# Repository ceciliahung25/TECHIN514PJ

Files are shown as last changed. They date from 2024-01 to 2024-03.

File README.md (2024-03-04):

# Echoes of Space

## Cecilia Hung (2320001)

For a detailed view of the power consumption calculations and system profiles, you can view the spreadsheet here:
[View the Power Consumption Spreadsheet](https://docs.google.com/spreadsheets/d/1GH_dmqcpy9LyMxHUE3kLtBWBAWlxp0ul/edit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)
This spreadsheet includes all the power metrics used in the project and the estimated days of use for each component.

### Sensing the Unseen: A Symphony in Silence

In the vast tapestry of everyday life, sounds weave invisible threads, creating a symphony often unheard and unseen. "Echoes of Space" is an odyssey into making the imperceptible palpable, visualizing the whispers and roars of our environment, and transforming them into a visual serenade.

### Sensing Device: Whisperer of the Unheard Symphony

The Sensing Device is engineered to capture ambient noise with precision and transmit this data for further processing. It serves as the primary data collection unit in diverse settings.

### Display Device: Illuminator of the Unseen Resonance

The Display Device is tasked with receiving acoustic data and rendering it into a visual format. It utilizes a range of components to articulate the nuances of environmental sound.

### Components

- **Sensing Device**
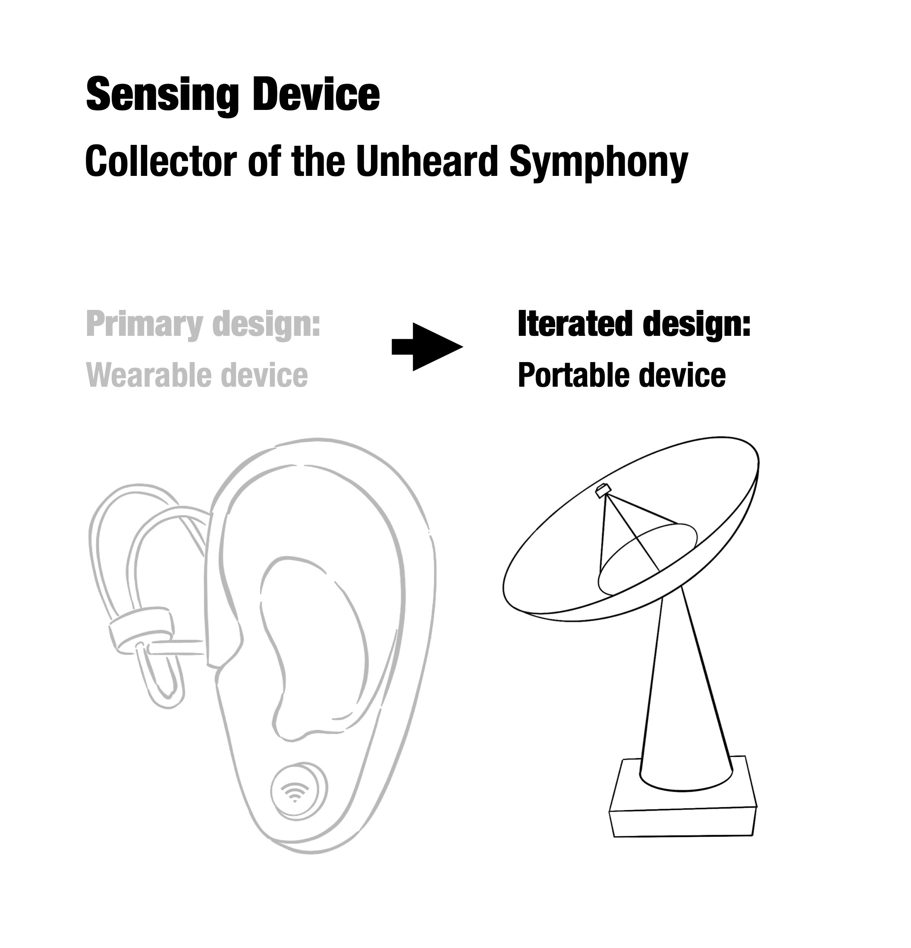
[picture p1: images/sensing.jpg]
Sensing Device

  - Microcontroller: Seeed Xiao ESP32S3
  - Microphone: Seeed Xiao ESP32S3 Sense Expansion Board Microphone
  - Interface: Adafruit Tactile Switch Button (12mm Square, 6mm Tall)

- **Display Device**
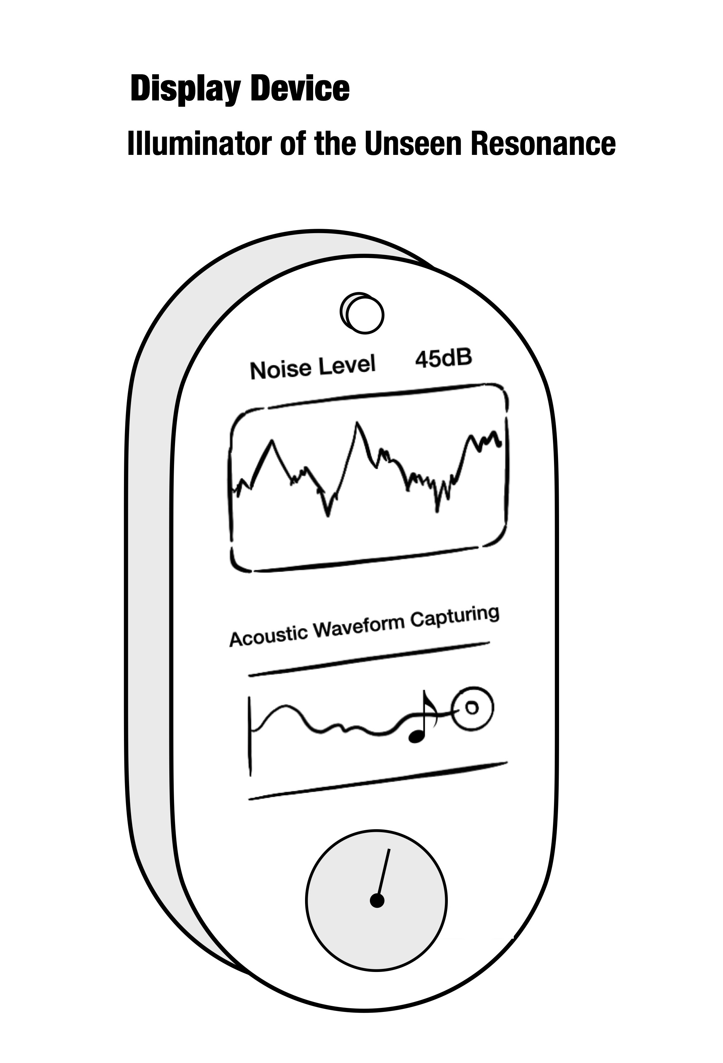
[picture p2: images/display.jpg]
Display Device

  - Microcontroller: Seeed Xiao ESP32S3
  - Display: OLED SSD1306
  - User Interface: Adafruit SPDT Slide Switch
  - Output Actuator: Stepper Motor (JST X27.168)
  - Power Source: 3.7V Lipo Battery 1000mAh

### System Architecture Diagram
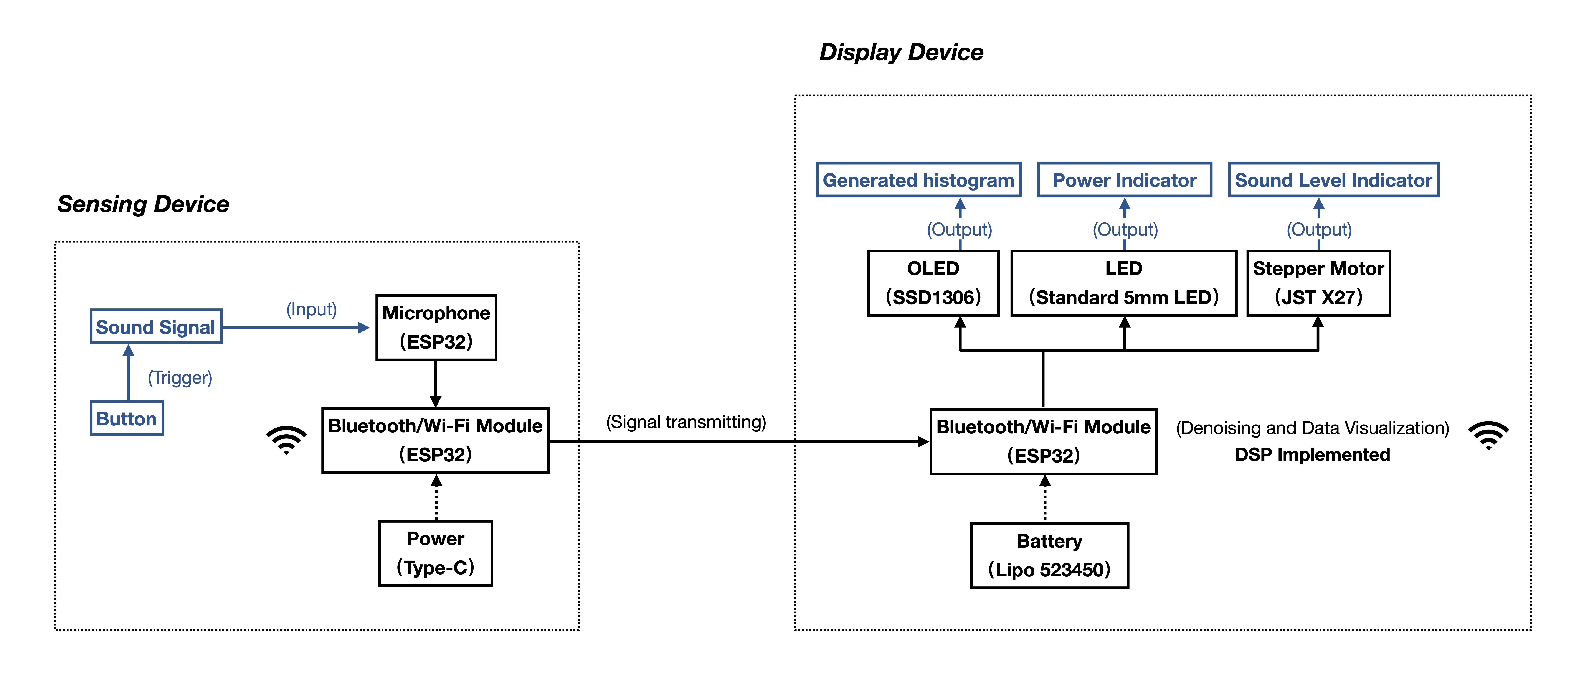
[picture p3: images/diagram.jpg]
System Architecture


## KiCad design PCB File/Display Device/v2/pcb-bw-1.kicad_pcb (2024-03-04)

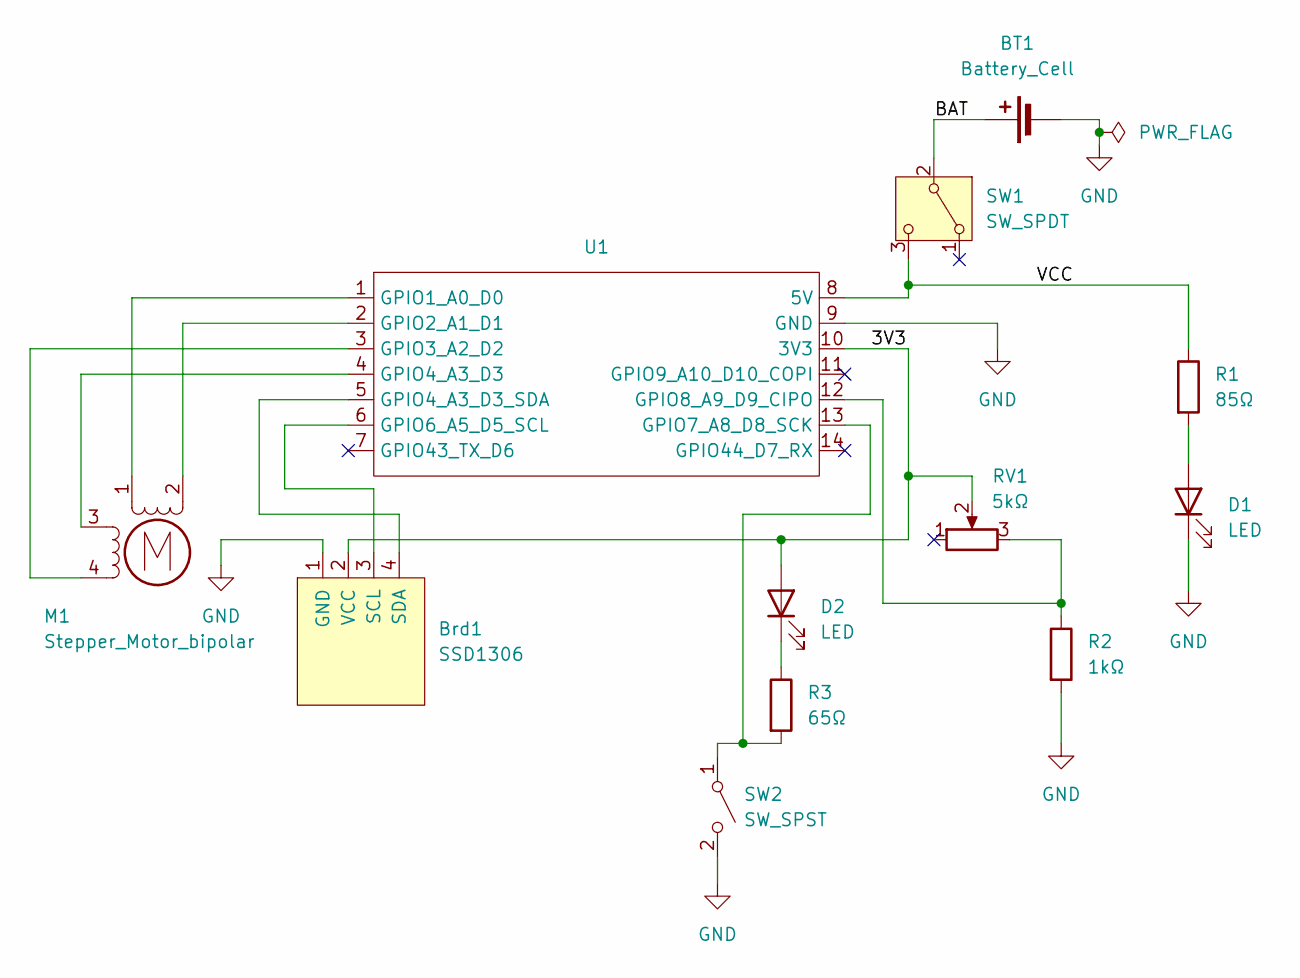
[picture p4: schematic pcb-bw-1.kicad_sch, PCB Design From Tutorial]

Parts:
BT1: Battery_Cell; JST_NV_B02P-NV_1x02_P5.00mm_Vertical
Brd1: SSD1306; 128x64OLED
D1, D2: LED; LED_0805_2012Metric_Pad1.15x1.40mm_HandSolder
M1: Stepper_Motor_bipolar; x27_stepper
R1: 85Ω; R_0805_2012Metric_Pad1.20x1.40mm_HandSolder
R2: 1kΩ; R_0805_2012Metric_Pad1.20x1.40mm_HandSolder
R3: 65Ω; R_0805_2012Metric_Pad1.20x1.40mm_HandSolder
RV1: 5kΩ; Potentiometer_Piher_PC-16_Single_Horizontal
SW1: SW_SPDT; JST_EH_B3B-EH-A_1x03_P2.50mm_Vertical
SW2: SW_SPST; SW_PUSH-12mm
U1: XIAO_ESP32_SENSE

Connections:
/3V3: Brd1.2 (VCC), D2.2 (A), RV1.2, U1.10 (3V3)
/BAT: BT1.1 (+), SW1.2 (B)
/VCC: R1.1, SW1.3 (C), U1.8 (5V)
GND: BT1.2 (-), Brd1.1 (GND), D1.1 (K), R2.2, SW2.2 (B), U1.9 (GND)
unnamed: Brd1.3 (SCL), U1.6 (GPIO6_A5_D5_SCL)
unnamed: Brd1.4 (SDA), U1.5 (GPIO4_A3_D3_SDA)
unnamed: D1.2 (A), R1.2
unnamed: D2.1 (K), R3.1
unnamed: M1.2 (-), U1.2 (GPIO2_A1_D1)
unnamed: R3.2, SW2.1 (A), U1.13 (GPIO7_A8_D8_SCK)
unnamed: M1.1, U1.1 (GPIO1_A0_D0)
unnamed: M1.4, U1.3 (GPIO3_A2_D2)
unnamed: M1.3, U1.4 (GPIO4_A3_D3)
unnamed: R2.1, RV1.3, U1.12 (GPIO8_A9_D9_CIPO)

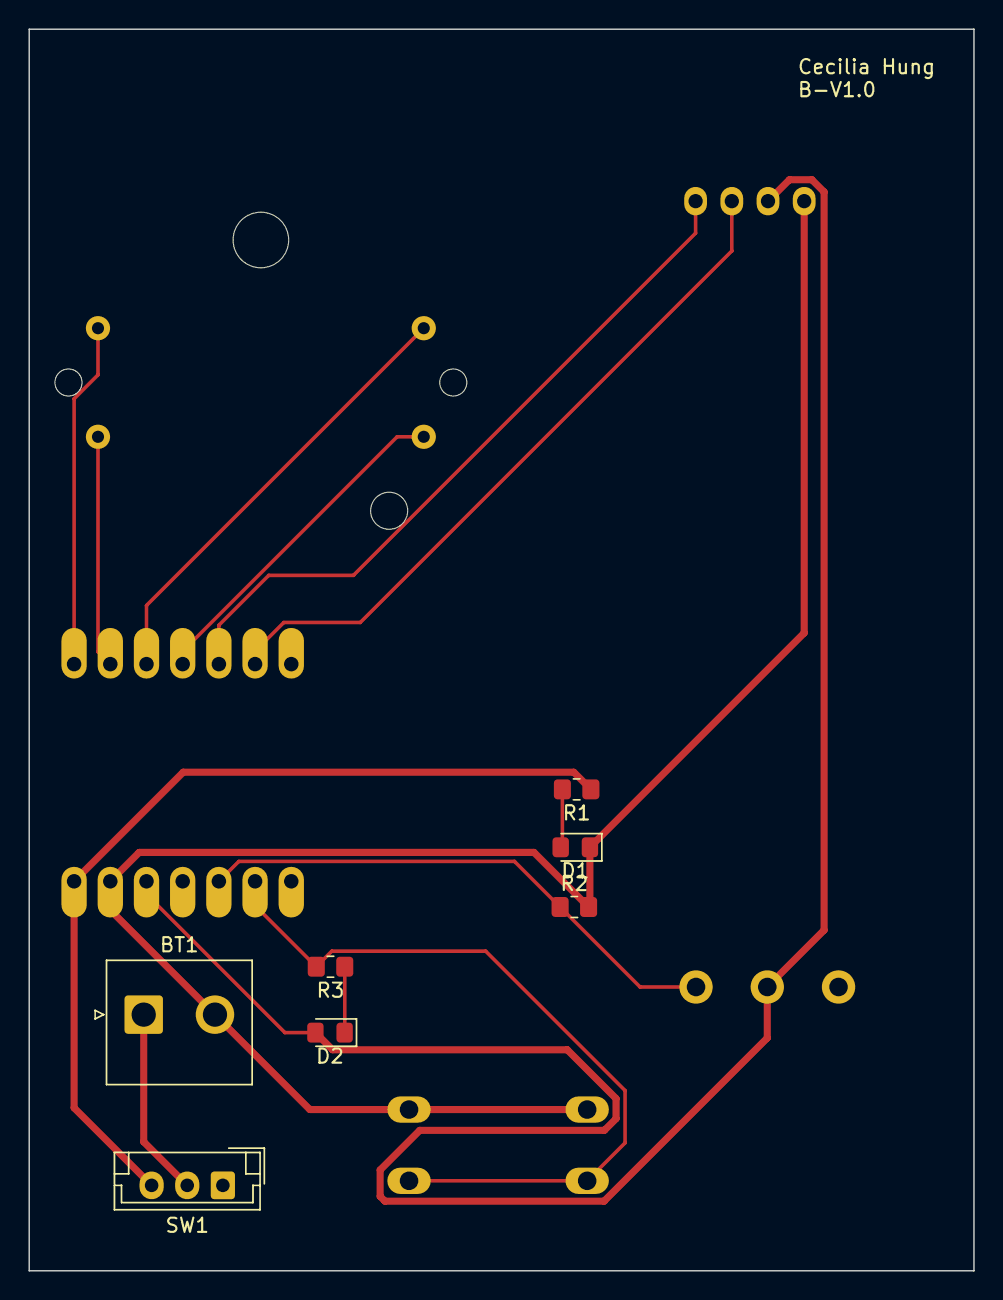
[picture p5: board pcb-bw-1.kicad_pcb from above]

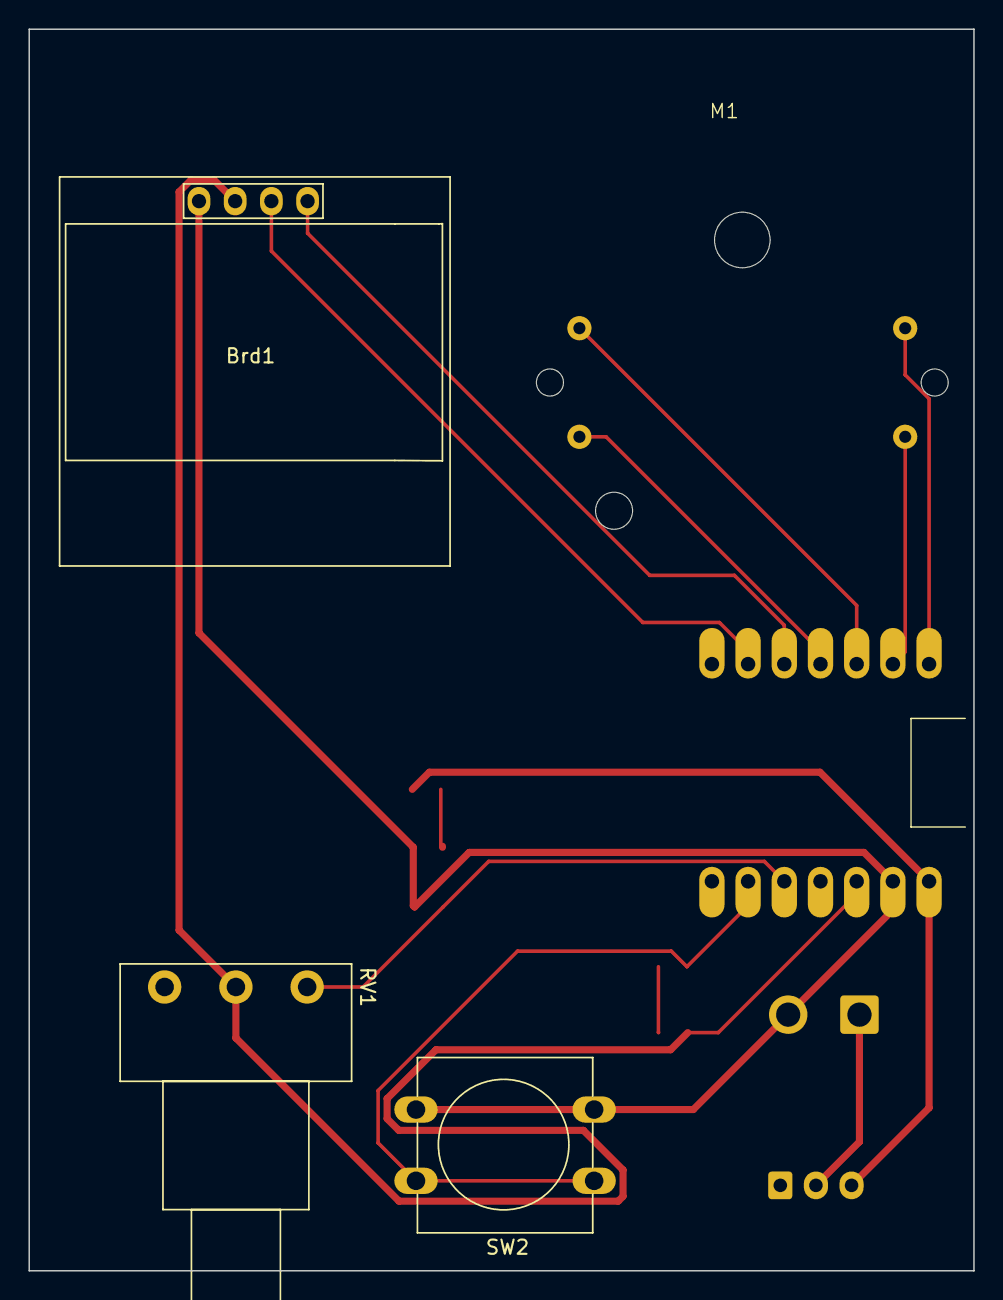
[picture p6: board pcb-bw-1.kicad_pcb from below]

Board: 2 copper layers, 66.3 x 87.1 mm, 12 parts (5 on the bottom side), 14 nets.

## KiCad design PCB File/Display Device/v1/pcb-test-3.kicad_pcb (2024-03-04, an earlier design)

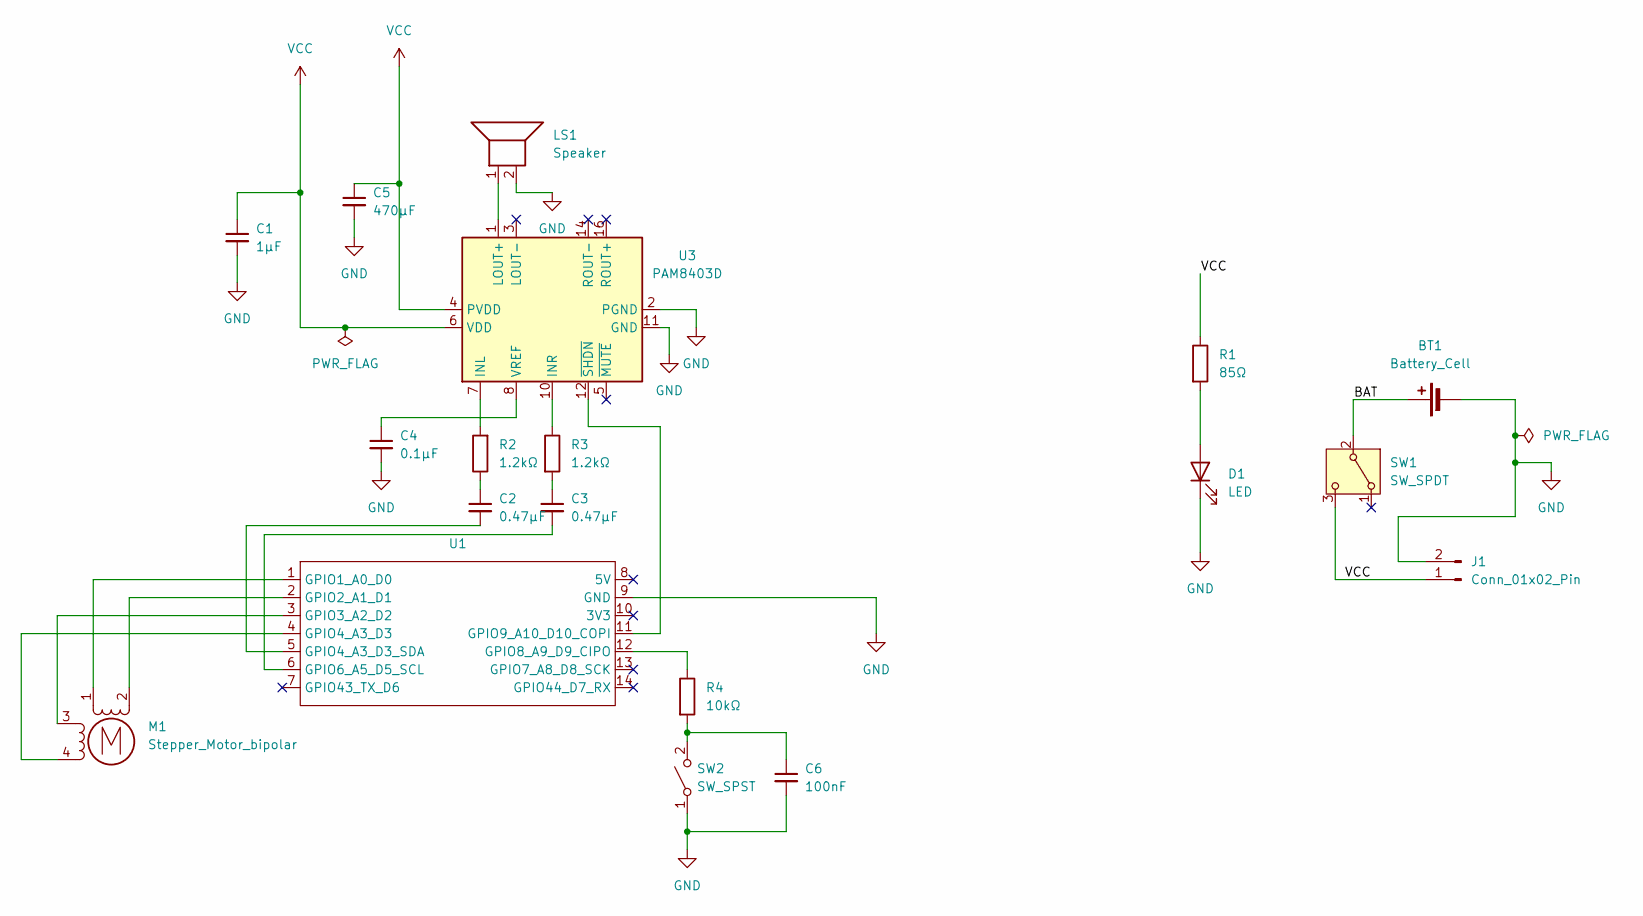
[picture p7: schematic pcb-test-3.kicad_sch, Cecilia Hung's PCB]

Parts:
BT1: Battery_Cell; JST_XA_B02B-XASK-1-A_1x02_P2.50mm_Vertical
C1: 1μF; C_0805_2012Metric_Pad1.18x1.45mm_HandSolder
C2, C3: 0.47μF; C_0805_2012Metric_Pad1.18x1.45mm_HandSolder
C4: 0.1μF; C_0805_2012Metric_Pad1.18x1.45mm_HandSolder
C5: 470μF; C_0805_2012Metric_Pad1.18x1.45mm_HandSolder
C6: 100nF; C_0805_2012Metric_Pad1.18x1.45mm_HandSolder
D1: LED; LED_0805_2012Metric_Pad1.15x1.40mm_HandSolder
J1: Conn_01x02_Pin; JST_NV_B02P-NV_1x02_P5.00mm_Vertical
LS1: Speaker; Pin_D1.2mm_L11.3mm_W3.0mm_Flat
M1: Stepper_Motor_bipolar; x27_stepper
R1: 85Ω; R_0805_2012Metric_Pad1.20x1.40mm_HandSolder
R2, R3: 1.2kΩ; R_0805_2012Metric_Pad1.20x1.40mm_HandSolder
R4: 10kΩ; R_0805_2012Metric_Pad1.20x1.40mm_HandSolder
SW1: SW_SPDT; JST_EH_B3B-EH-A_1x03_P2.50mm_Vertical
SW2: SW_SPST; SW_PUSH-12mm
U1: XIAO_ESP32_SENSE
U3: PAM8403D; SOP-16_3.9x9.9mm_P1.27mm

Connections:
/BAT: BT1.1 (+), SW1.2 (B)
GND: BT1.2 (-), C1.2, C4.2, C5.2, C6.2, D1.1 (K), J1.2, LS1.2, SW2.1 (A), U1.9 (GND), U3.2 (PGND), U3.11 (GND), U3.15 (PGND)
unnamed: C2.1, R2.1
unnamed: C3.1, R3.2
unnamed: D1.2 (A), R1.2
unnamed: M1.2 (-), U1.2 (GPIO2_A1_D1)
unnamed: C6.1, R4.2, SW2.2 (B)
unnamed: M1.1, U1.1 (GPIO1_A0_D0)
unnamed: M1.3, U1.3 (GPIO3_A2_D2)
unnamed: M1.4, U1.4 (GPIO4_A3_D3)
unnamed: C2.2, U1.5 (GPIO4_A3_D3_SDA)
unnamed: C3.2, U1.6 (GPIO6_A5_D5_SCL)
unnamed: R4.1, U1.12 (GPIO8_A9_D9_CIPO)
unnamed: U1.11 (GPIO9_A10_D10_COPI), U3.12 (~SHDN)
unnamed: R2.2, U3.7 (INL)
unnamed: R3.1, U3.10 (INR)
unnamed: LS1.1, U3.1 (LOUT+)
unnamed: C4.1, U3.8 (VREF)
VCC: C1.1, C5.1, J1.1, R1.1, SW1.3 (C), U3.4 (PVDD), U3.6 (VDD), U3.13 (PVDD)

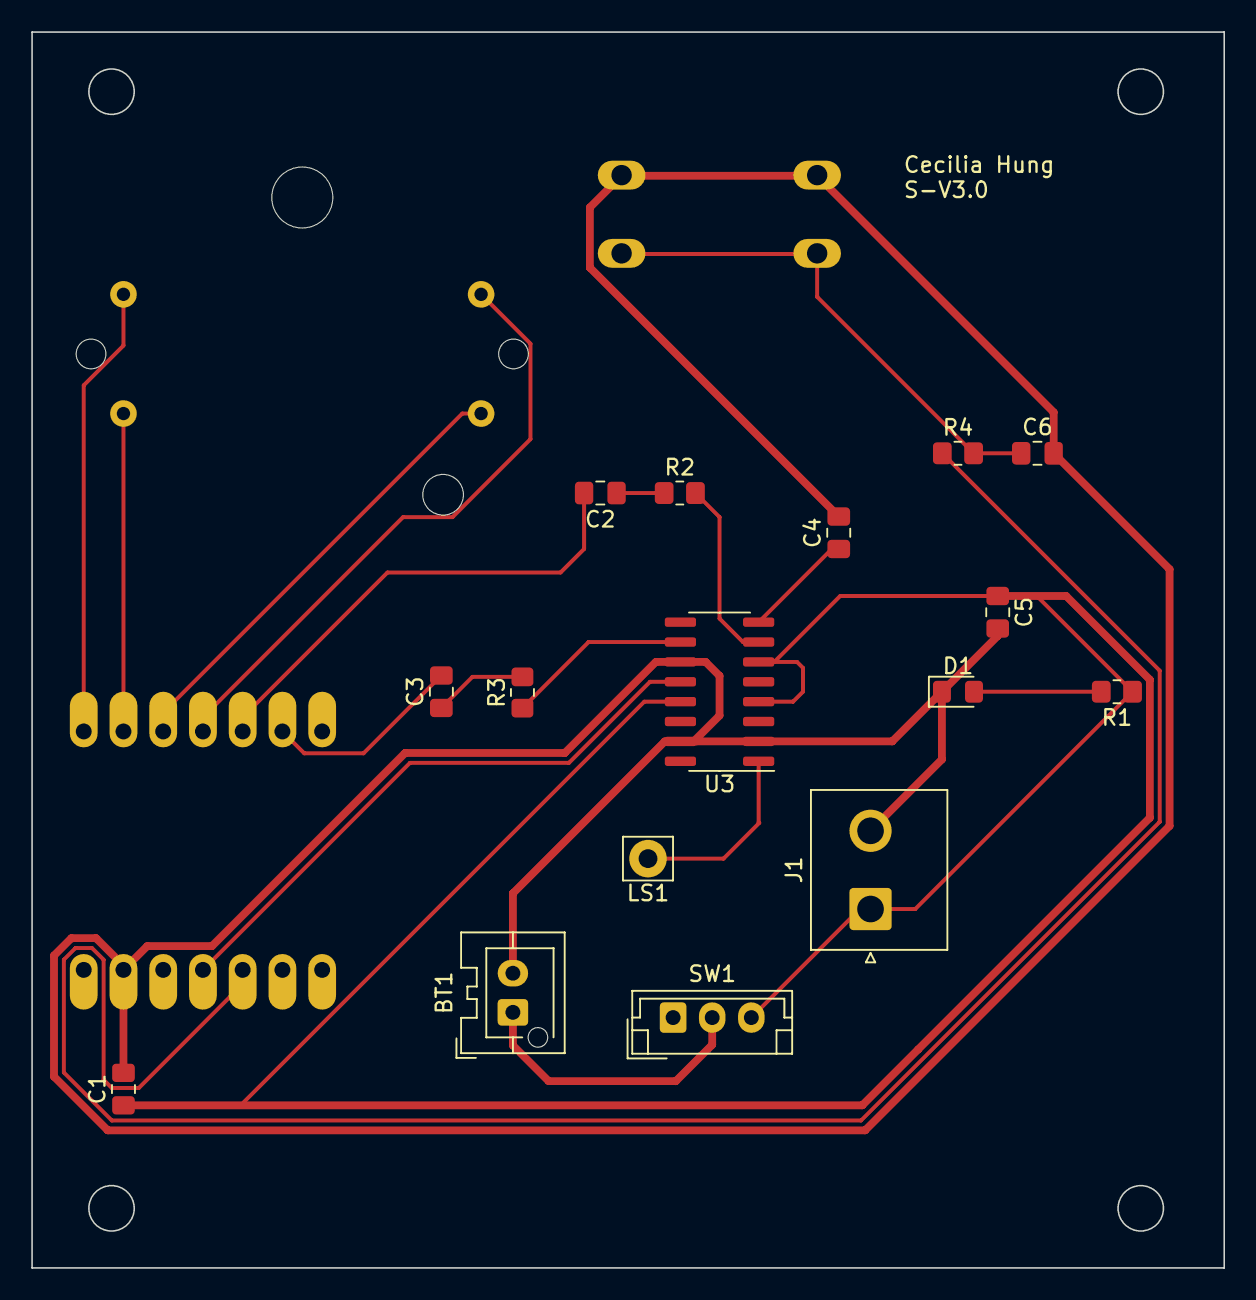
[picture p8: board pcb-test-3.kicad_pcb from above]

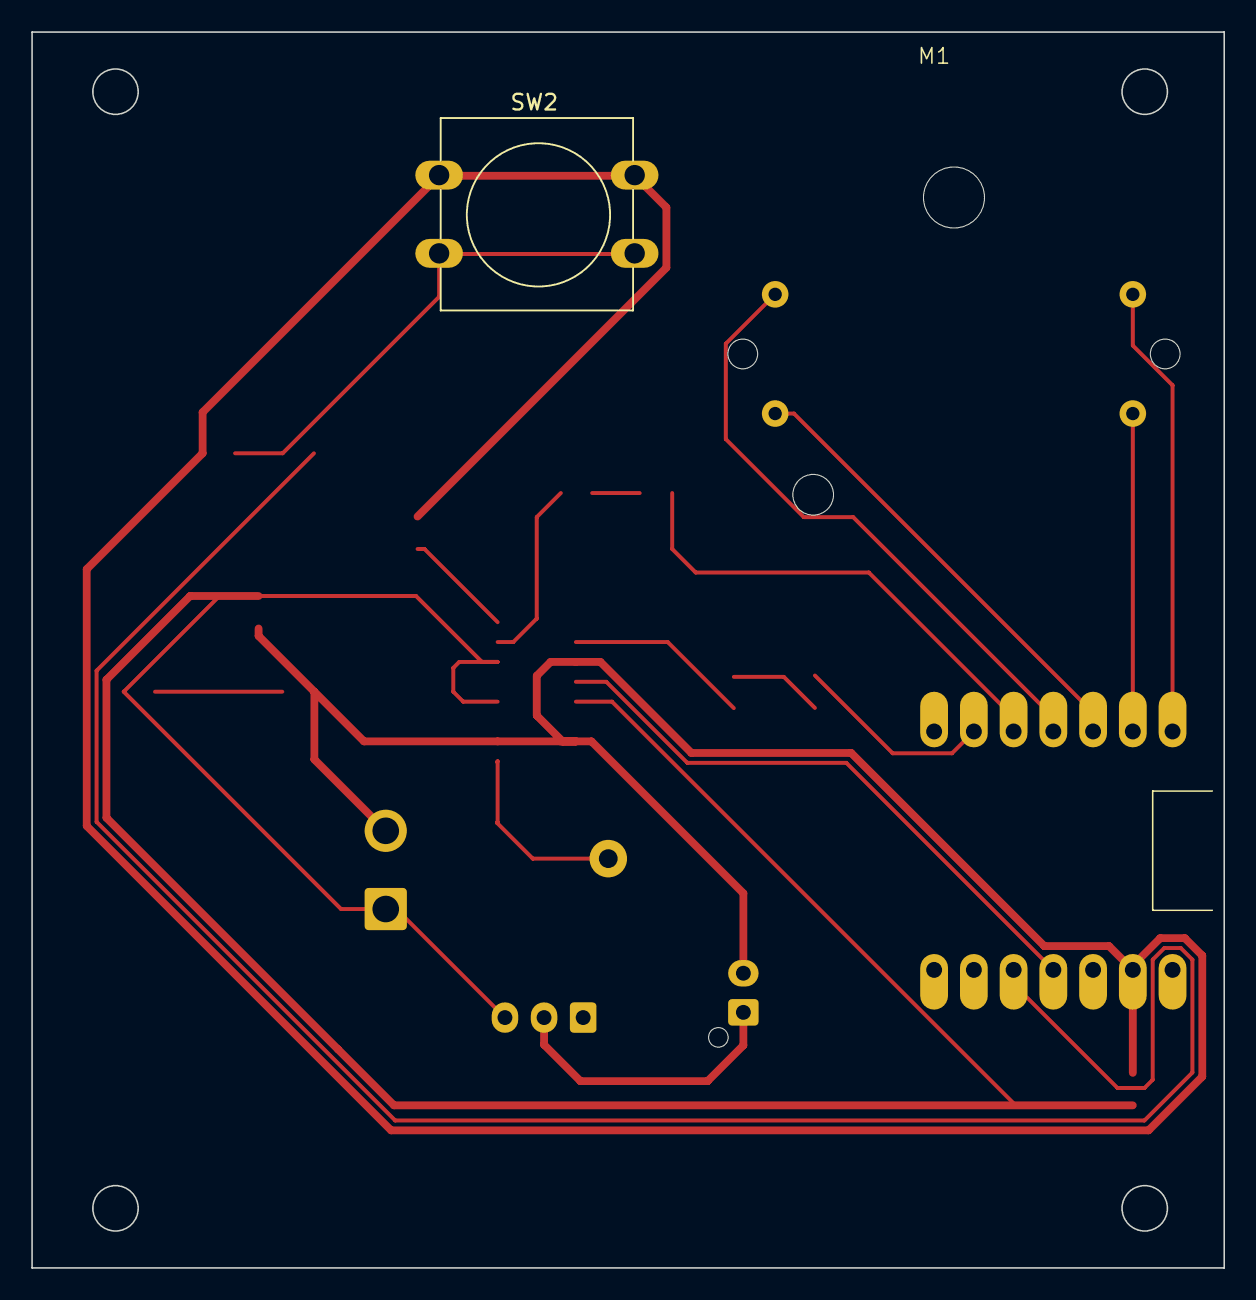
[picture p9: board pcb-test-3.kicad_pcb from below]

Board: 2 copper layers, 76.2 x 79.0 mm, 19 parts (3 on the bottom side), 19 nets.

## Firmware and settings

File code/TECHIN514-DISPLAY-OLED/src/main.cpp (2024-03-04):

#include <Arduino.h>
#include <Wire.h>
#include <Adafruit_GFX.h>
#include <Adafruit_SSD1306.h>
#include <WiFi.h>
#include <SwitecX25.h>

#define SCREEN_WIDTH 128 // OLED display width, in pixels
#define SCREEN_HEIGHT 64 // OLED display height, in pixels
#define OLED_RESET -1    // Define OLED reset pin (may not be needed for your display)
#define STEPS 945        // Define the steps for the motor

// Motor pin definitions
const int motorPin1 = 1;
const int motorPin2 = 2;
const int motorPin3 = 3;
const int motorPin4 = 4;

Adafruit_SSD1306 display(SCREEN_WIDTH, SCREEN_HEIGHT, &Wire, OLED_RESET);
SwitecX25 motor(STEPS, motorPin1, motorPin2, motorPin3, motorPin4);

const char* ssid = "ESP32_Sensing_Device";
const char* password = "yourPassword";
const char* serverIP = "192.168.4.1";
const uint16_t serverPort = 1234;

WiFiClient client;

const int maxDataPoints = 20;
float rmsData[maxDataPoints];
int dataIndex = 0;
float currentRMS = 0.0;

void drawHistogram();
void updateMotorPosition(float rmsValue);

void setup(void) {
    Serial.begin(9600);
    if (!display.begin(SSD1306_SWITCHCAPVCC, 0x3C)) {
        Serial.println(F("SSD1306 allocation failed"));
        for (;;);
    }
    display.display();
    delay(2000);

    WiFi.begin(ssid, password);
    while (WiFi.status() != WL_CONNECTED) {
        delay(1000);
        Serial.println("Connecting to WiFi...");
    }
    Serial.println("Connected to WiFi");

    // Initialize the rmsData array
    for (int i = 0; i < maxDataPoints; i++) {
        rmsData[i] = 0.0;
    }

    // Initialize the motor
    motor.zero();
}

void loop(void) {
    static float lastRMS = -1.0;

    if (!client.connected()) {
        if (!client.connect(serverIP, serverPort)) {
            delay(1000);
            return;
        }
        client.println("Request data");
    }

    if (client.available()) {
        String line = client.readStringUntil('\n');
        if (line.length() > 0 && line != "\r") {
            int commaIndex = line.indexOf(',');
            currentRMS = line.substring(0, commaIndex).toFloat();

            if (currentRMS != lastRMS) {
                lastRMS = currentRMS;

                // Store RMS data and update the index
                rmsData[dataIndex] = currentRMS;
                dataIndex = (dataIndex + 1) % maxDataPoints;

                // Update OLED display
                display.clearDisplay();
                display.setTextSize(1);
                display.setTextColor(WHITE);
                display.setCursor(0, 0);
                display.print("RMS Volume: ");
                display.println(currentRMS);

                // Draw histogram
                drawHistogram();

                // Update motor position
                updateMotorPosition(currentRMS);

                display.display();
            }
        }
    }

    // Update the motor position
    motor.update();
}

void drawHistogram() {
    int barWidth = SCREEN_WIDTH / maxDataPoints;
    for (int i = 0; i < maxDataPoints; i++) {
        int barHeight = map(rmsData[(dataIndex + i) % maxDataPoints], 0, 25, 0, SCREEN_HEIGHT / 2);
        display.drawRect(SCREEN_WIDTH - (i + 1) * barWidth, SCREEN_HEIGHT - barHeight, barWidth - 1, barHeight, WHITE);
    }
}

void updateMotorPosition(float rmsValue) {
    int targetPosition;
    if (rmsValue >= 0 && rmsValue <= 15) {
        targetPosition = STEPS / 3; // 1/3 full rotation
    } else if (rmsValue > 15 && rmsValue <= 20) {
        targetPosition = (2 * STEPS) / 3; // 2/3 full rotation
    } else if (rmsValue > 20) {
        targetPosition = STEPS - 1; // Full rotation
    }
    motor.setPosition(targetPosition);
}

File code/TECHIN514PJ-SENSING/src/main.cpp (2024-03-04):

#include <Arduino.h>
#include <WiFi.h>
#include <I2S.h>
#include "FS.h"
#include "SD.h"
#include "SPI.h"

#define BUTTON_PIN D7
#define RECORD_TIME 5
#define WAV_FILE_NAME "/arduino_rec.wav"
#define SAMPLE_RATE 16000U
#define SAMPLE_BITS 16
#define WAV_HEADER_SIZE 44
#define ALPHA 0.1 // Low-pass filter constant (0 < ALPHA < 1)

const char* ssid = "ESP32_Sensing_Device";
const char* password = "yourPassword";
WiFiServer server(1234);

float rmsValue = 0.0;
float zcrValue = 0.0;

float calculateRMS(const uint8_t* buffer, size_t bufferSize);
float calculateZCR(const uint8_t* buffer, size_t bufferSize);
void generate_wav_header(uint8_t *header, uint32_t size, uint32_t rate);
void record_wav();
float lowPassFilter(float currentValue, float newValue);

void setup() {
    Serial.begin(115200);
    pinMode(BUTTON_PIN, INPUT_PULLUP);

    // Initialize I2S
    I2S.setAllPins(-1, 42, 41, -1, -1);
    if (!I2S.begin(PDM_MONO_MODE, SAMPLE_RATE, SAMPLE_BITS)) {
        Serial.println("Failed to initialize I2S!");
        while (1);
    }

    // Initialize SD card
    if (!SD.begin(21)) {
        Serial.println("Failed to mount SD card!");
        while (1);
    }

    // Set up Wi-Fi network
    WiFi.mode(WIFI_AP);
    WiFi.softAP(ssid, password);
    Serial.println("Wi-Fi Access Point started");
    Serial.print("AP IP address: ");
    Serial.println(WiFi.softAPIP());

    // Start the server
    server.begin();
    Serial.println("Server started");
}

void loop() {
    if (digitalRead(BUTTON_PIN) == LOW) {
        delay(50);
        if (digitalRead(BUTTON_PIN) == LOW) {
            Serial.println("Button pressed, starting recording...");
            record_wav();
        }
    }

    // Check for Wi-Fi clients
    WiFiClient client = server.available();
    if (!client) {
        return;
    }

    Serial.println("Client connected");
    while (client.connected()) {
        if (client.available()) {
            String request = client.readStringUntil('\n');
            if (request.indexOf("Request data") >= 0) {
                String dataToSend = String(rmsValue) + "," + String(zcrValue);
                client.println(dataToSend);
                Serial.println("Data sent over Wi-Fi: " + dataToSend);
            }
            client.stop();
            Serial.println("Client disconnected");
        }
    }
}

void record_wav() {
    Serial.println("Starting recording...");
    uint32_t record_size = (SAMPLE_RATE * SAMPLE_BITS / 8) * RECORD_TIME;
    uint8_t *rec_buffer = (uint8_t *)ps_malloc(record_size);
    if (rec_buffer == NULL) {
        Serial.println("Memory allocation failed!");
        return;
    }

    // Reset filter values before new recording
    rmsValue = 0.0;
    zcrValue = 0.0;

    File file = SD.open(WAV_FILE_NAME, FILE_WRITE);
    if (!file) {
        Serial.println("Failed to open file for writing.");
        free(rec_buffer);
        return;
    }

    uint8_t wav_header[WAV_HEADER_SIZE];
    generate_wav_header(wav_header, record_size, SAMPLE_RATE);
    file.write(wav_header, WAV_HEADER_SIZE);

    size_t bytes_read = I2S.readBytes(rec_buffer, record_size);
    Serial.print("Bytes read: ");
    Serial.println(bytes_read);

    if (bytes_read > 0) {
        float newRMS = calculateRMS(rec_buffer, bytes_read);
        float newZCR = calculateZCR(rec_buffer, bytes_read);

        rmsValue = lowPassFilter(rmsValue, newRMS);
        zcrValue = lowPassFilter(zcrValue, newZCR);

        Serial.print("RMS Volume: ");
        Serial.println(rmsValue);
        Serial.print("Zero Crossing Rate (Frequency): ");
        Serial.println(zcrValue);
    } else {
        Serial.println("No data recorded.");
    }

    file.write(rec_buffer, bytes_read);
    file.close();
    free(rec_buffer);
}

float calculateRMS(const uint8_t* buffer, size_t bufferSize) {
    long sum = 0;
    for (size_t i = 0; i < bufferSize; i += 2) {
        int16_t sample = (int16_t)(buffer[i] | (buffer[i + 1] << 8));
        sum += sample * sample;
    }
    return sqrt(sum / (bufferSize / 2));
}

float calculateZCR(const uint8_t* buffer, size_t bufferSize) {
    int zeroCrossings = 0;
    for (size_t i = 2; i < bufferSize; i += 2) {
        int16_t sample1 = (int16_t)(buffer[i - 2] | (buffer[i - 1] << 8));
        int16_t sample2 = (int16_t)(buffer[i] | (buffer[i + 1] << 8));
        if ((sample1 > 0 && sample2 < 0) || (sample1 < 0 && sample2 > 0)) {
            zeroCrossings++;
        }
    }
    return (float)zeroCrossings * SAMPLE_RATE / bufferSize;
}

void generate_wav_header(uint8_t *header, uint32_t size, uint32_t rate) {
    // [Your existing generate_wav_header function]
}

float lowPassFilter(float currentValue, float newValue) {
    return ALPHA * newValue + (1 - ALPHA) * currentValue;
}

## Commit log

2024-01-18 Added PCB folder
    [test-1-B_Cu.gbr, test-1-B_Mask.gbr, test-1-B_Paste.gbr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]
2024-01-25 Updated”
    [pcb-test-3-B_Cu.gbr, pcb-test-3-B_Mask.gbr, pcb-test-3-B_Paste.gbr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]
2024-02-01 “Updated”
